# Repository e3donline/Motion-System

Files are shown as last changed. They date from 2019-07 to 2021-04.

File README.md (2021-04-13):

# Motion System
STPs / STLs / DXFs / PDFs

Copyright (C) E3D-Online Ltd (e3d-online.com) These files are free hardware you can redistribute it and / or modify it under the terms of the General Public License as published by the Free Software Foundation, either version 3 of the License, or (at your option) any later version.

13/04/21 - Added Bowden Hemera Bracket.

10/02/21 - Adapted MS-ELEC-PANEL from Titan to Hemera.

05/08/19 - Added README.md to the STLs folder  

02/08/19 - Added assembly drawings

31/07/19 - Added step files of printed parts

30/07/19 - Initial Upload

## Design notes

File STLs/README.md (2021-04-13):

Print the required number of parts as listed below.

4 x Spool Bar.stl   (This part can be replaced with a 90mm length of 8mm round bar).

2 x Hemera Bowden Bracket.stl for each Bowden Hemera.

4 x Spool Carrier.stl  
4 x Filament Pick-Up.stl  
1 x IEC Bracket.stl  
1 x IEC Socket.stl  
1 x Motor Cable Cover.stl  
1 x PSU Duct.stl  
1 x Cable Blank.stl  
1 x Wiper.stl  
  
Typical slicer settings.  
  
0.20 Layer height.  
0.40 Nozzle.  
3 Perimeters.  
5 Top Layers.  
5 Bottom Layers.  
12% Infil.  
  
Print with your favourite material.

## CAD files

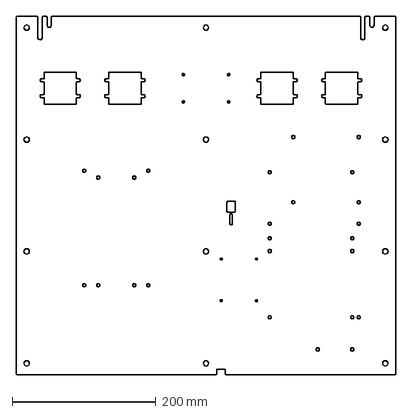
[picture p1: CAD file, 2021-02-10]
DXFs/MS-ELEC-PANEL-PUBLIC-1.3.dxf
529.0 x 499.0 mm

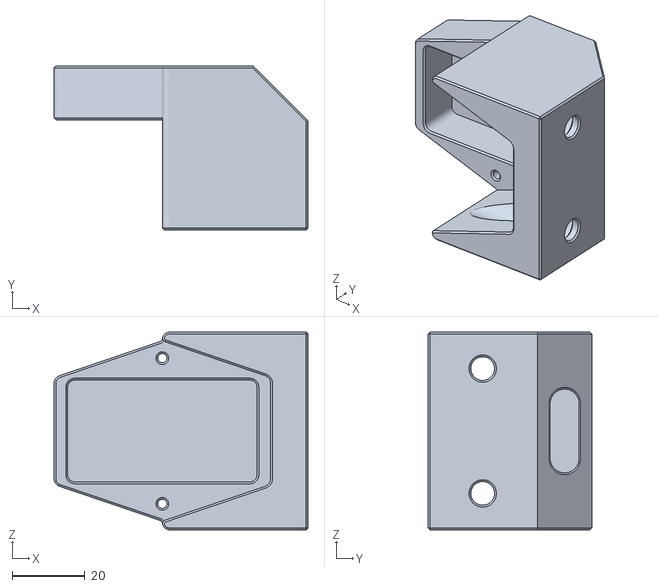
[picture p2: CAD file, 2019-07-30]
STLs/IEC Bracket.stl
69.8 x 45.0 x 54.3

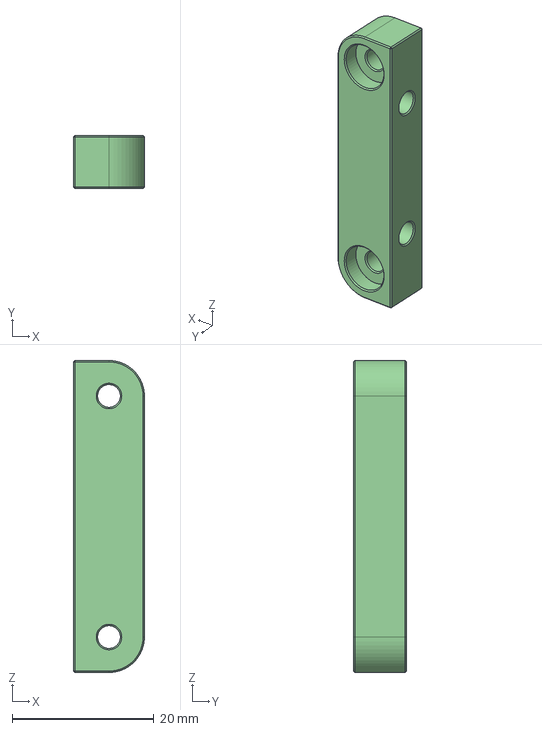
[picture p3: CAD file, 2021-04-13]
STPs/Hemera Bowden Bracket.step
10.0 x 7.50 x 44.0 mm

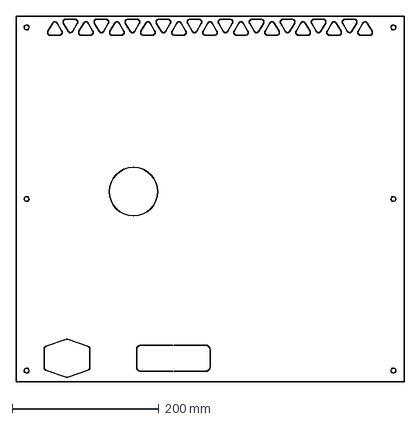
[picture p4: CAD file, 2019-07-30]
DXFs/MS-REAR-PANEL 1.0.dxf
529.0 x 499.0 mm

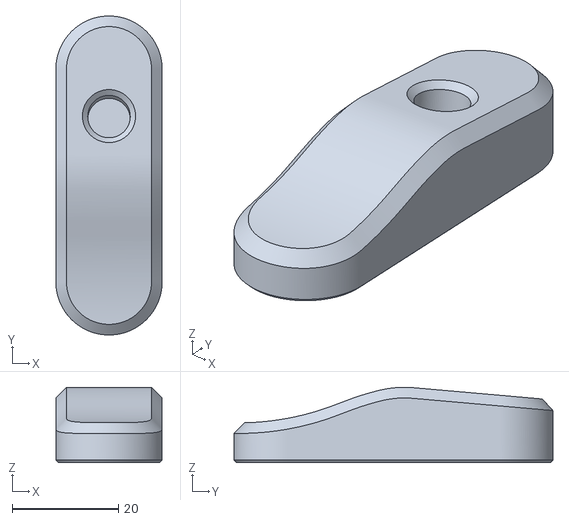
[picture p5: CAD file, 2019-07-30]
STLs/Spool Carrier.stl
20.0 x 60.0 x 14.2

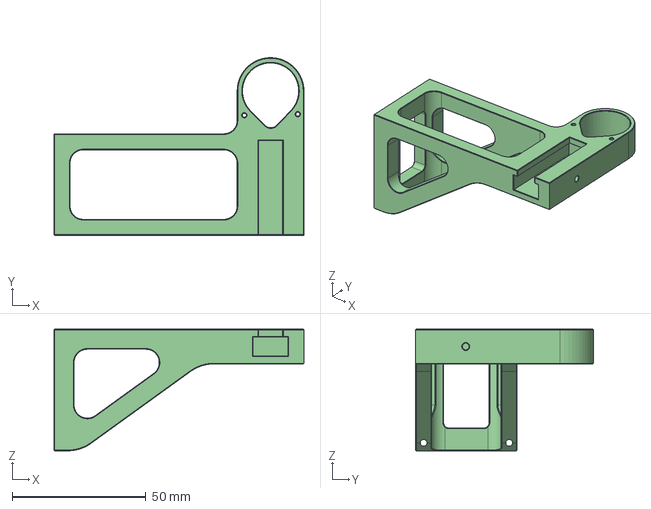
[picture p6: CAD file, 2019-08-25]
STPs/Wiper.step
93.5 x 66.5 x 45.5 mm

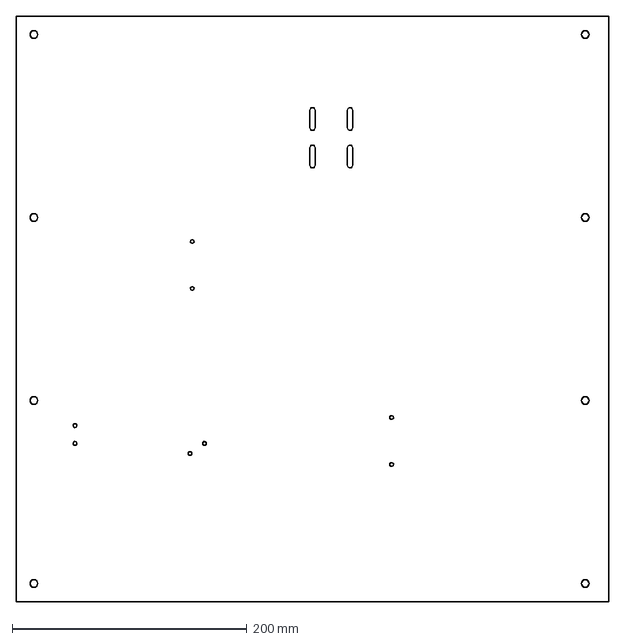
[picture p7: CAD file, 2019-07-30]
DXFs/MS-SIDE-PANEL 1.0.dxf
505.0 x 499.0 mm

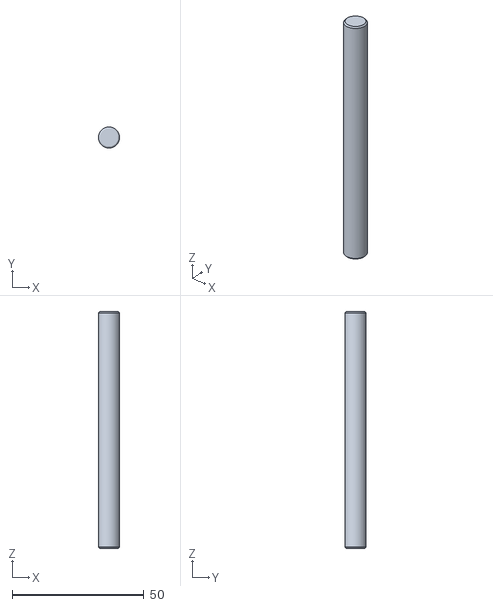
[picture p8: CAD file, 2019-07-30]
STLs/Spool Bar.stl
8.00 x 7.99 x 90.0

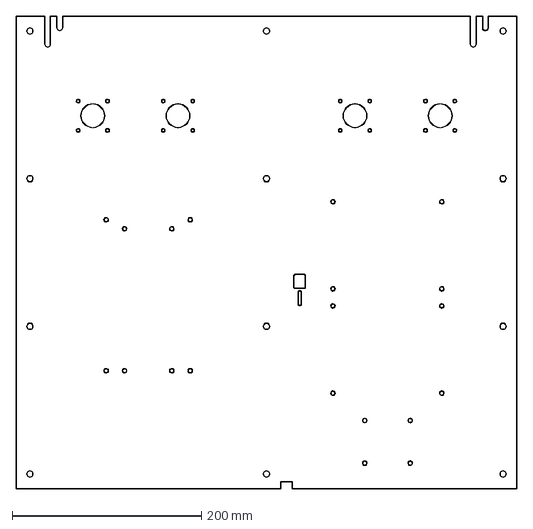
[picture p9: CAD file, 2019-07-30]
DXFs/MS-ELEC-PANEL 1.0.dxf
529.0 x 499.0 mm

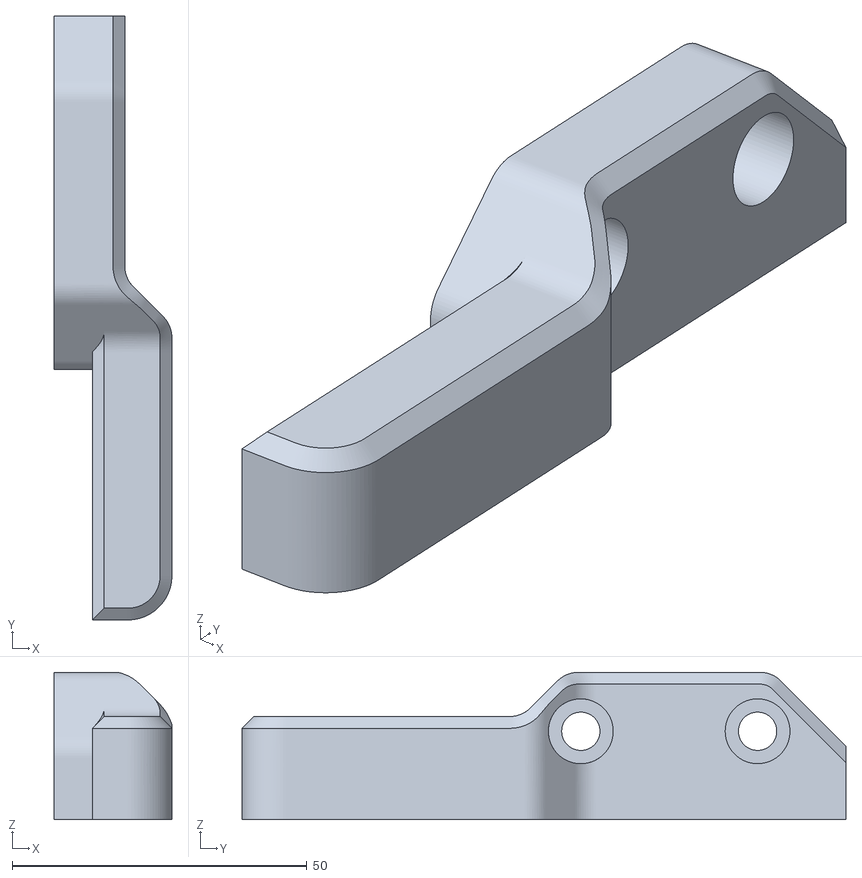
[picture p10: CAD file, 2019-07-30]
STLs/Motor Cable Cover.stl
20.0 x 102.5 x 25.0

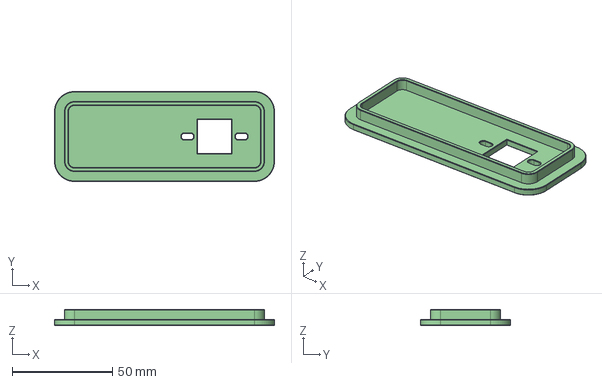
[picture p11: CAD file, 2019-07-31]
STPs/Cable Blank RJ45.step
110.0 x 45.0 x 8.00 mm

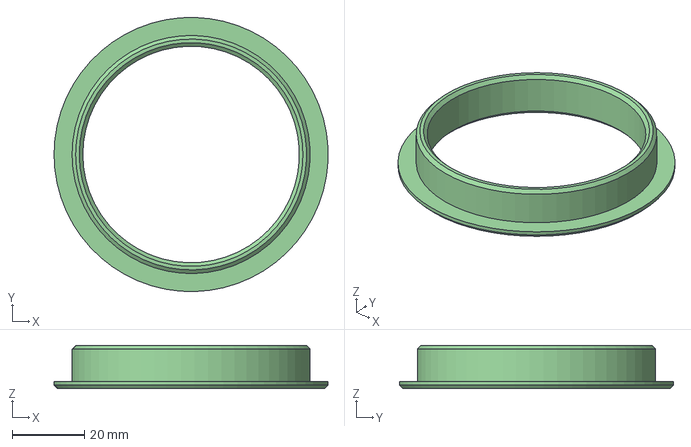
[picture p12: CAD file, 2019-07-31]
STPs/PSU Duct.step
75.9 x 76.0 x 12.0 mm

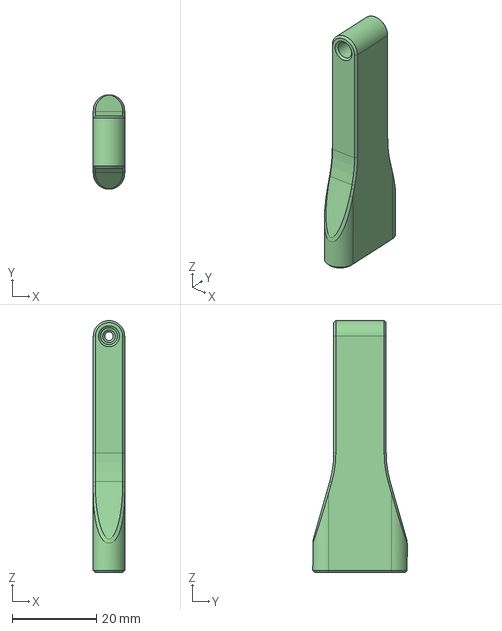
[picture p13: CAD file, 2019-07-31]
STPs/Filament Pick-Up.step
7.50 x 22.5 x 60.0 mm

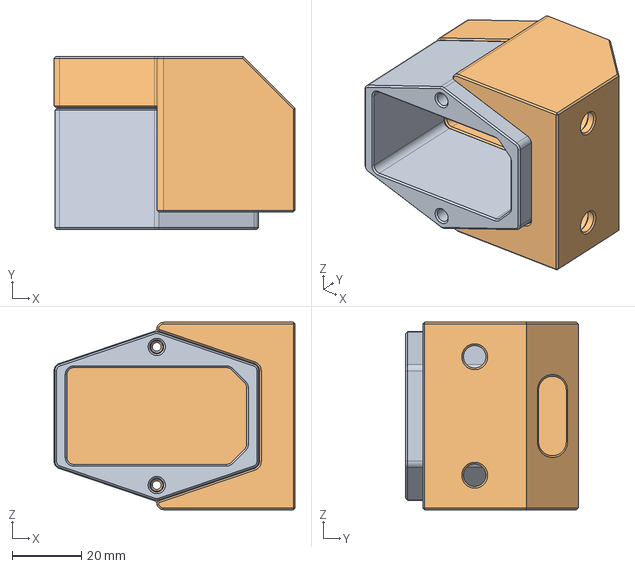
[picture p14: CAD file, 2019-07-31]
STPs/IEC Socket.step
69.8 x 50.0 x 54.3 mm

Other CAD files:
STPs/Spool Carrier Bracket .step
STPs/Z-Axis Motor Cable Cover.step
STPs/Cable Blank.step
STPs/Nozzle Brush.step
DXFs/MS-BASE-PLATE 1.4.dxf
DXFs/MS-TOP-PLATE 1.6.dxf
STLs/Cable Blank.stl
STLs/Filament Pick-Up.stl
STLs/Hemera Bowden Bracket.stl
STLs/IEC Socket.stl
STLs/PSU Duct.stl
STLs/Wiper.stl
STPs/8X90 Spool Bar.step
STPs/MS-BASE-PLATE 1.4.step
STPs/MS-BED-BRACKET 1.4.step
STPs/MS-BED-PLATE 1.3.step
STPs/MS-BELT-CLAMP-IM 1.2.step
STPs/MS-LONG-PULLEY-STANDOFF 1.3.step
STPs/MS-MOTOR-SPACE-LONG 1.1.step
STPs/MS-MOTOR-SPACE-SHORT 1.1.step
STPs/MS-SHAFT-BOLT 1.4.step
STPs/MS-SHORT-PULLEY-STANDOFF 1.3.step
STPs/MS-SOFF-M3-FF-24L 1.1.step
STPs/MS-TENSION-ARM 1.0.step
STPs/MS-TENSION-BLOCK 1.1.step
STPs/MS-TOP-PLATE 1.6.step
STPs/MS-X-BAR-ALU 1.3.step
STPs/MS-X-BELT-PLATE 1.6.step
STPs/MS-X-BLOCK 1.3.step
STPs/MS-X-SPACER 1.1.step
STPs/MS-XY-STOP 1.1.step
STPs/MS-Z-MOTOR-BRACKET 1.1.step
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

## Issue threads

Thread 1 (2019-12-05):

STEP Assemblies

Parallax91, 2019-12-05:
Would it be possible to add a STEP of the full assembly? STEPs of the major sub-assemblies might be equally useful. I understand that this makes it harder to keep the repository up to date, but it would be nice. The same goes for the tool changer, but I won't post this request twice.

e3donline, 2019-12-06:
A member of the community has already done this | https://www.thingiverse.com/thing:3880296

Closed 2019-12-06.

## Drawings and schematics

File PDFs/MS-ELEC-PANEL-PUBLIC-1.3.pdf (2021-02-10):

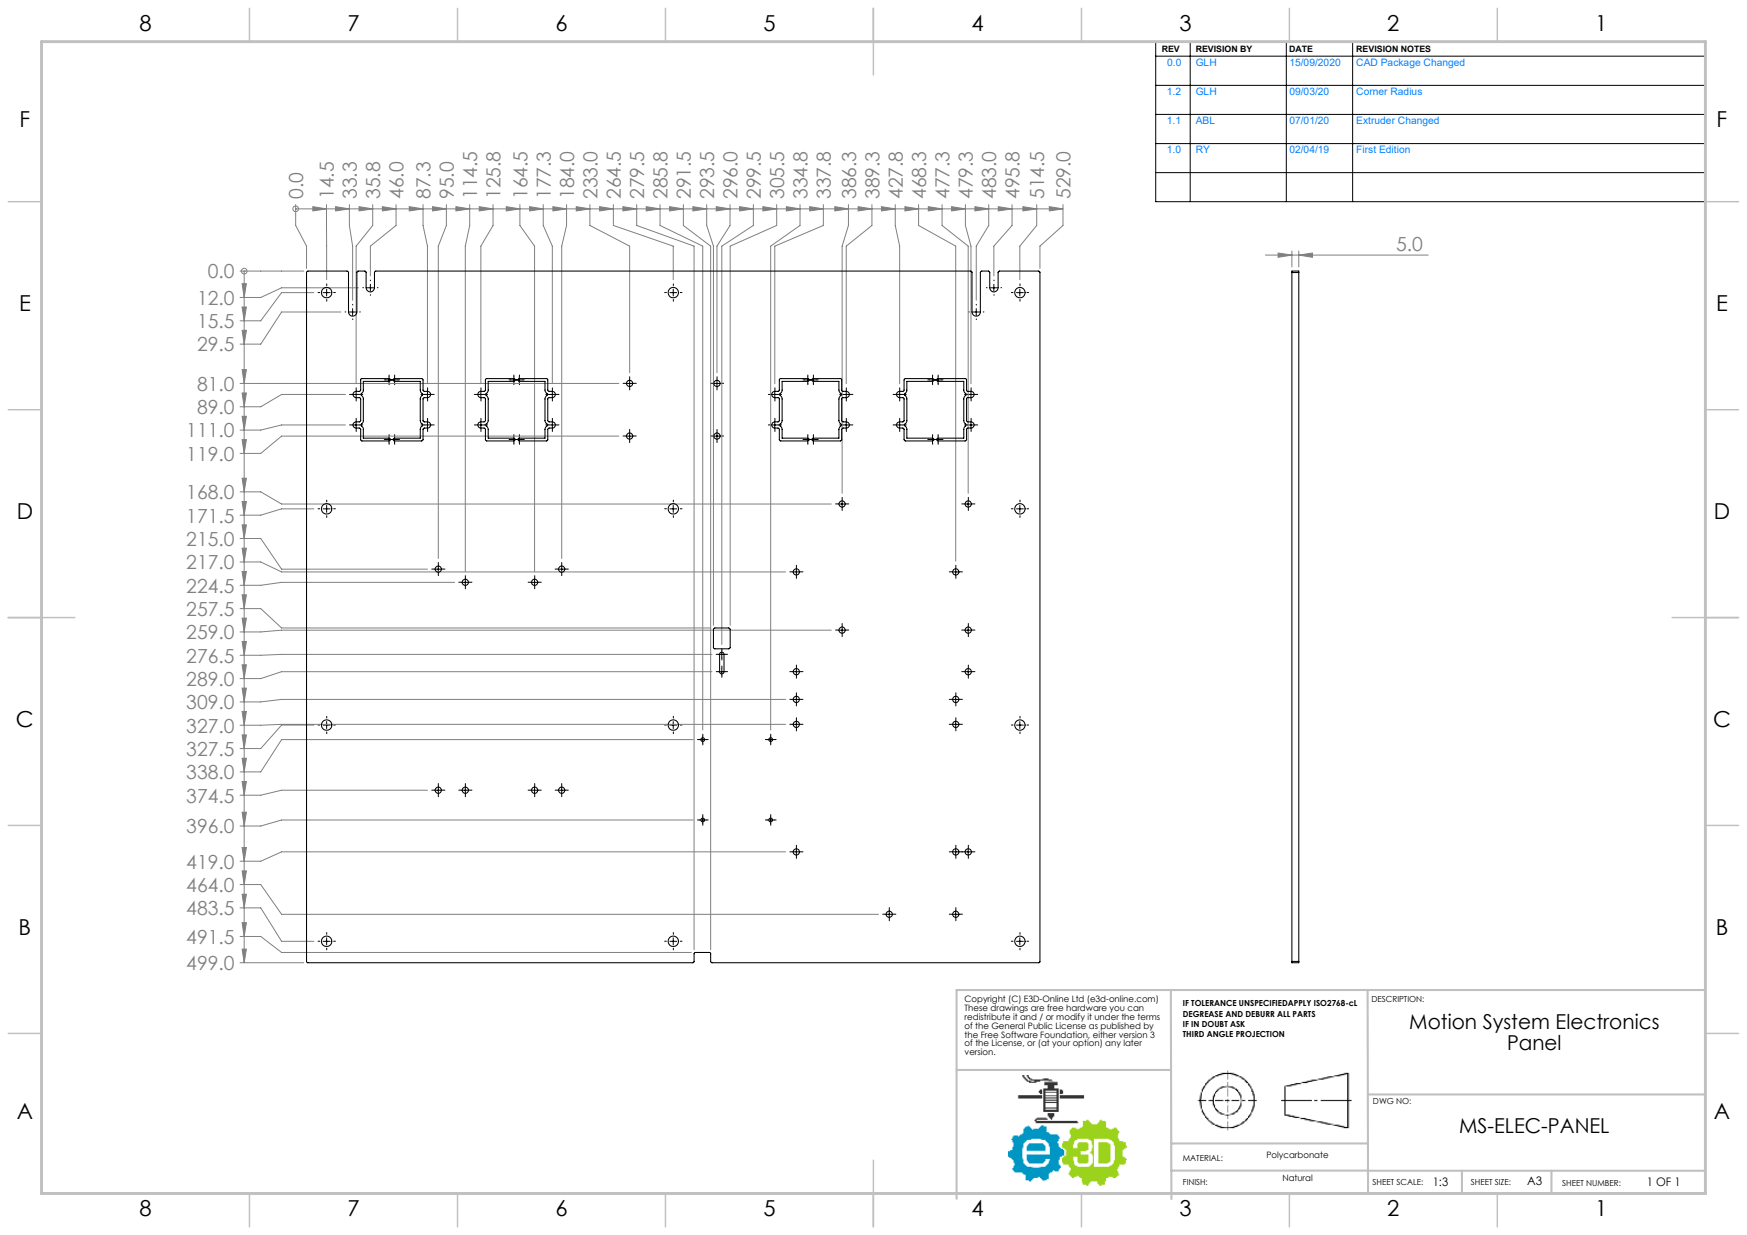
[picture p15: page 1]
DWG NO:; SHEET SCALE:; SHEET SIZE:; SHEET NUMBER:

REV | REVISION BY | DATE | REVISION NOTES
0.0 | GLH | 15/09/2020 | CAD Package Changed

1.2 | GLH | 09/03/20 | Corner Radius

1.1 | ABL | 07/01/20 | Extruder Changed

1.0 | RY | 02/04/19 | First Edition

Copyright (C) E3D-Online Ltd (e3d-online.com)
These drawings are free hardware you can
redistribute it and / or modify it under the terms
of the General Public License as published by
the Free Software Foundation, either version 3
of the License, or (at your option) any later
version.

IF TOLERANCE UNSPECIFIEDAPPLY ISO2768-cL
DEGREASE AND DEBURR ALL PARTS
IF IN DOUBT ASK
THIRD ANGLE PROJECTION

DESCRIPTION:
Motion System Electronics

MS-ELEC-PANEL

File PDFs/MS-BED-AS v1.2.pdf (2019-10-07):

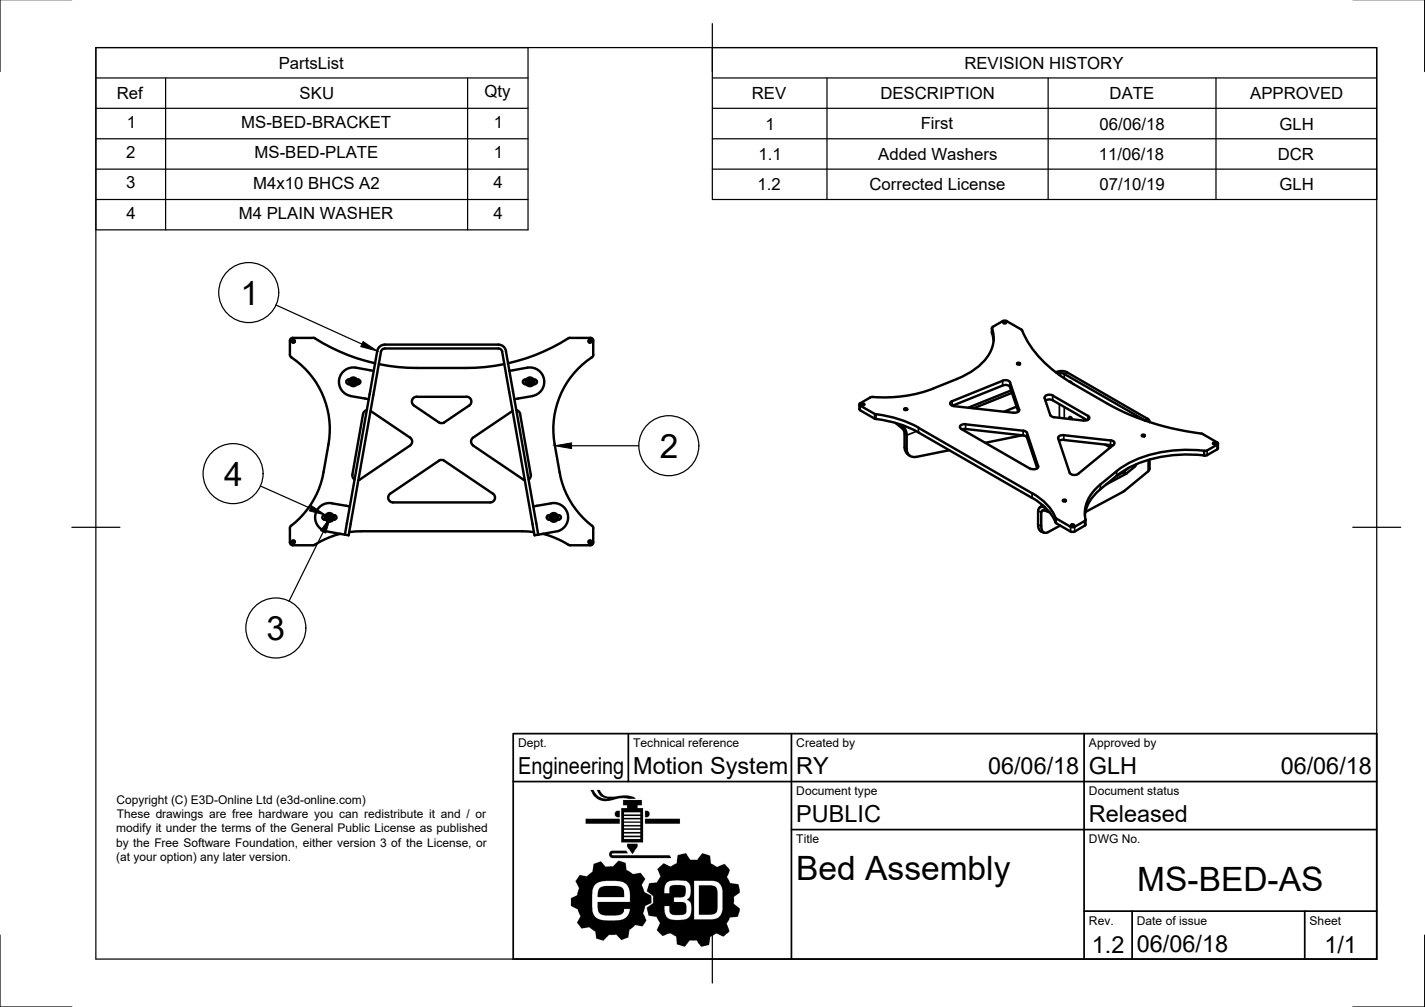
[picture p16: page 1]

PartsList | | REVISION HISTORY

Ref | SKU | Qty | REV | DESCRIPTION | DATE | APPROVED
1 | MS-BED-BRACKET | 1 | 1 | First | 06/06/18 | GLH
2 | MS-BED-PLATE | 1 | 1.1 | Added Washers | 11/06/18 | DCR
3 | M4x10 BHCS A2 | 4 | 1.2 | Corrected License | 07/10/19 | GLH
4 | M4 PLAIN WASHER | 4

Dept. Engineering | Technical reference Motion System | Created by RY 06/06/18 | Approved by GLH 06/06/18

Document type PUBLIC | Document status Released

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

Title | DWG No. MS-BED-AS Bed Assembly

Rev. 1.2 | Date of issue 06/06/18 | Sheet 1/1

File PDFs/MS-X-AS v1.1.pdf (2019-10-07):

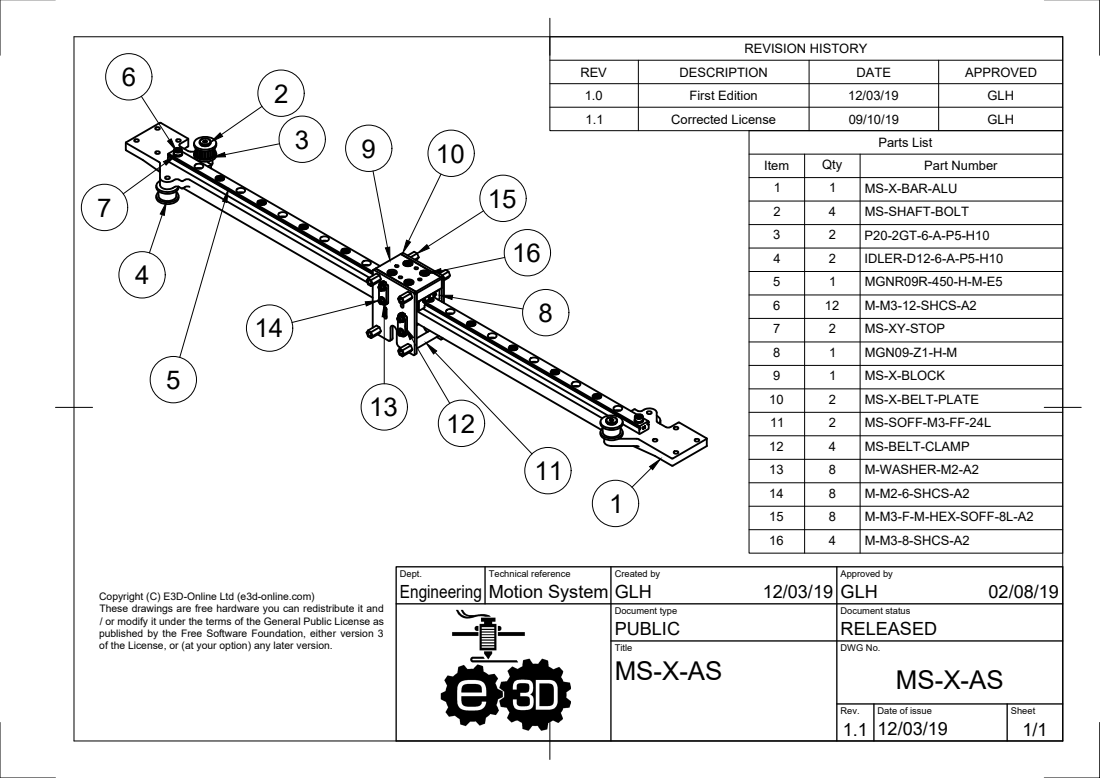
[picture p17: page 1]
Parts List

REVISION HISTORY

REV | DESCRIPTION | DATE | APPROVED
1.0 | First Edition | 12/03/19 | GLH
1.1 | Corrected License | 09/10/19 | GLH

Item | Qty | Part Number
1 | 1 | MS-X-BAR-ALU
2 | 4 | MS-SHAFT-BOLT
3 | 2 | P20-2GT-6-A-P5-H10
4 | 2 | IDLER-D12-6-A-P5-H10
5 | 1 | MGNR09R-450-H-M-E5
6 | 12 | M-M3-12-SHCS-A2
7 | 2 | MS-XY-STOP
8 | 1 | MGN09-Z1-H-M
9 | 1 | MS-X-BLOCK
10 | 2 | MS-X-BELT-PLATE
11 | 2 | MS-SOFF-M3-FF-24L
12 | 4 | MS-BELT-CLAMP
13 | 8 | M-WASHER-M2-A2
14 | 8 | M-M2-6-SHCS-A2
15 | 8 | M-M3-F-M-HEX-SOFF-8L-A2
16 | 4 | M-M3-8-SHCS-A2

Dept. Engineering | Technical reference Motion System | Created by GLH 12/03/19 | Approved by GLH 02/08/19

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

Document type PUBLIC | Document status RELEASED

of the License, or (at your option) any later version.

Title MS-X-AS | DWG No. MS-X-AS

Rev. 1.1 | Date of issue 12/03/19 | Sheet 1/1

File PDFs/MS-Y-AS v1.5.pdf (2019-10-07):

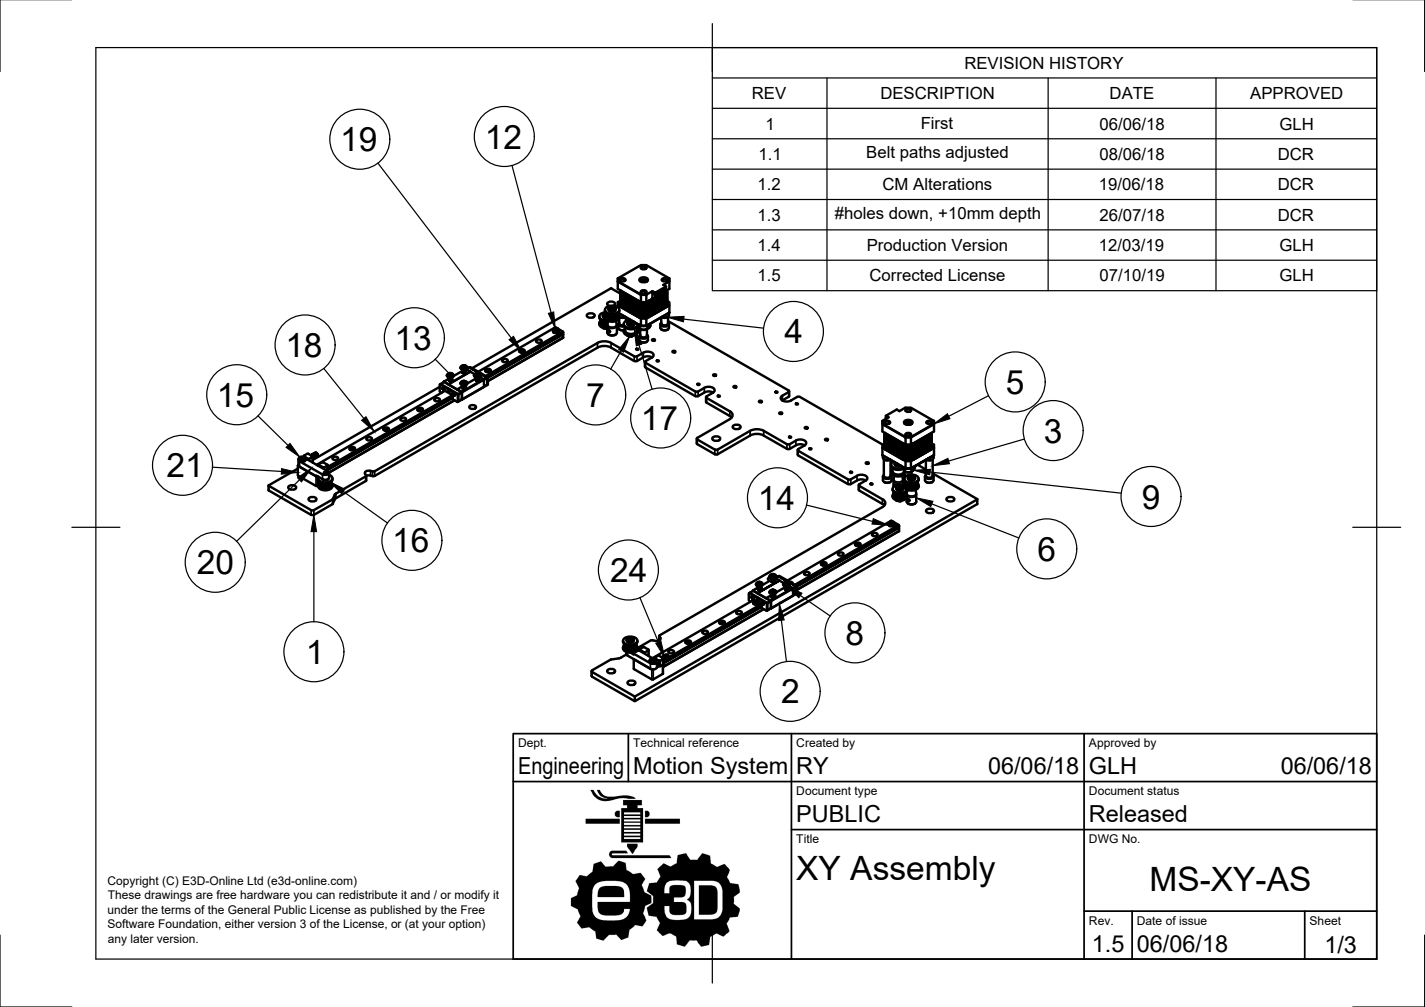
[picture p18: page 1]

REVISION HISTORY

REV | DESCRIPTION | DATE | APPROVED
1 | First | 06/06/18 | GLH
1.1 | Belt paths adjusted | 08/06/18 | DCR

1.2 | CM Alterations | 19/06/18 | DCR
1.3 | #holes down, +10mm depth | 26/07/18 | DCR

1.4 | Production Version | 12/03/19 | GLH
1.5 | Corrected License | 07/10/19 | GLH

Dept. Engineering | Technical reference Motion System | Created by RY 06/06/18 | Approved by GLH 06/06/18

Document type PUBLIC | Document status Released

Title | DWG No. MS-XY-AS XY Assembly

Copyright (C) E3D-Online Ltd (e3d-online.com)
These drawings are free hardware you can redistribute it and / or modify it
under the terms of the General Public License as published by the Free
Software Foundation, either version 3 of the License, or (at your option)
any later version.

Rev. 1.5 | Date of issue 06/06/18 | Sheet 1/3

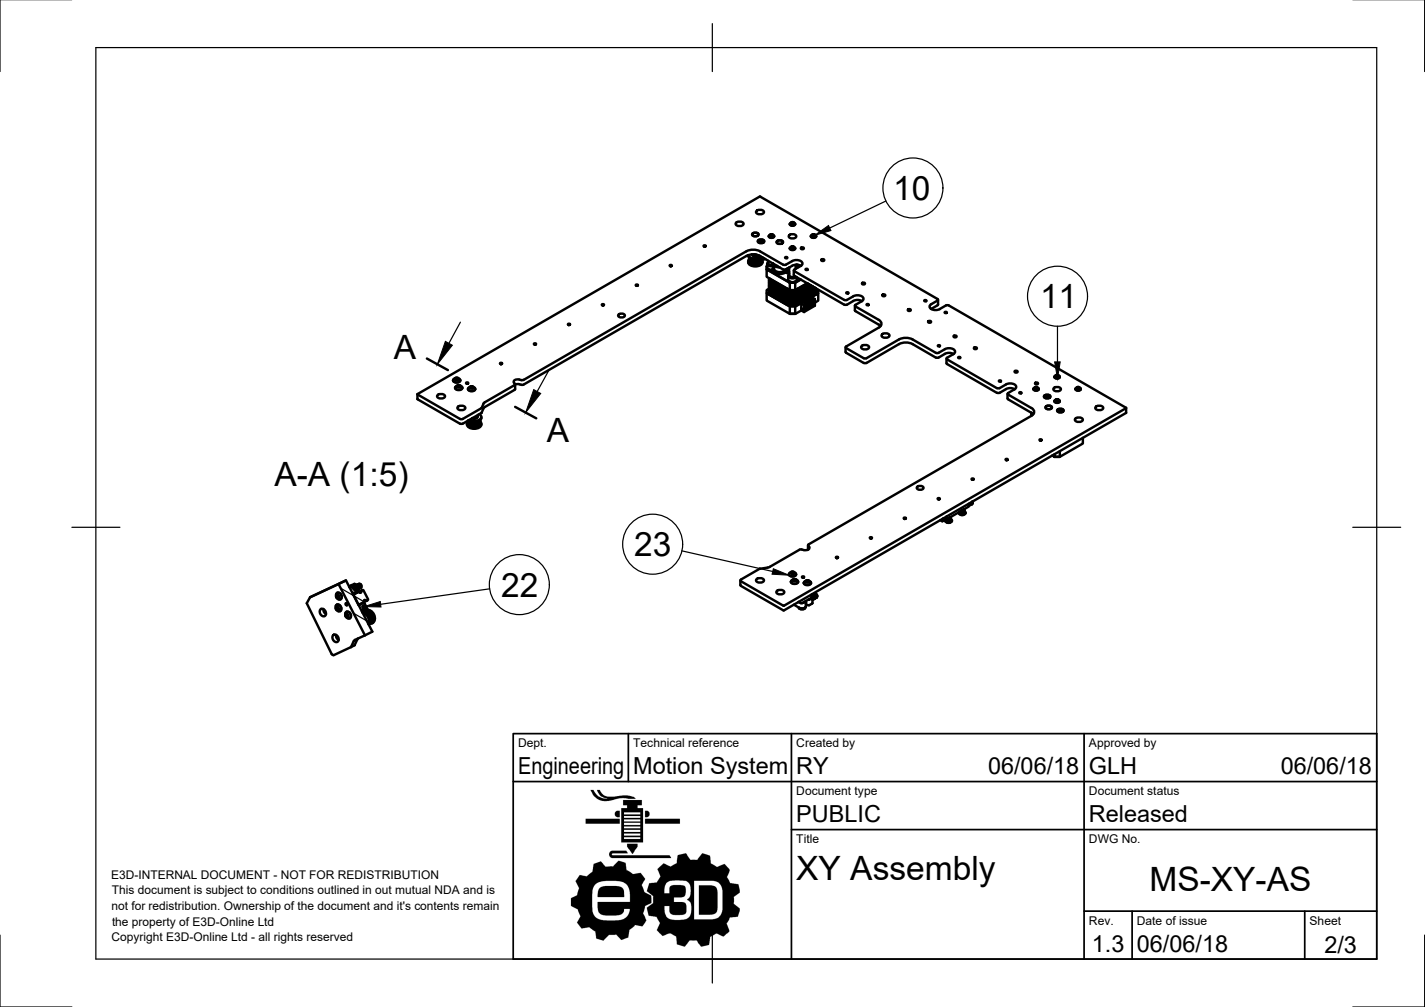
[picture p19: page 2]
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

Document type PUBLIC | Document status Released

Title | DWG No. MS-XY-AS XY Assembly

E3D-INTERNAL DOCUMENT - NOT FOR REDISTRIBUTION
This document is subject to conditions outlined in out mutual NDA and is
not for redistribution. Ownership of the document and it's contents remain
the property of E3D-Online Ltd
Copyright E3D-Online Ltd - all rights reserved

Rev. 1.3 | Date of issue 06/06/18 | Sheet 2/3

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

## Parts List

Item | Qty | Part Number
1 | 1 | MS-TOP-PLATE
2 | 2 | MGN12H-Z0-H-M
3 | 4 | MS-MOTOR-SPACE-LONG
4 | 4 | MS-MOTOR-SPACE-SHORT
5 | 2 | MS17HD2P4200
6 | 3 | MS-LONG-PULLEY-STANDOFF
7 | 3 | MS-SHORT-PULLEY-STANDOFF
8 | 8 | M-WASHER-M3-A2
9 | 2 | GT2 16T 5mm Bore Pulley
10 | 4 | M-M3-45-BHCS-A2
11 | 4 | M-M3-30-BHCS-A2
12 | 4 | M-M3-12-SHCS-A2
13 | 8 | M-M3-10-BHCS-A2
14 | 4 | MS-XY-STOP
15 | 10 | MS-SHAFT-BOLT
16 | 6 | P20-2GT-6-A-P5-H10
17 | 2 | IDLER-D12-6-A-P5-H10
18 | 2 | MGNR12R-360-H-M-E5
19 | 12 | M-M3-8-SHCS-A2
20 | 2 | MS-TENSION-ARM
21 | 2 | MS-TENSION-BLOCK
22 | 2 | M-M4-8-SHGS-A2
23 | 6 | M-M4-12-BHCS-A2
24 | 2 | M-M4-16-SHGS-A2

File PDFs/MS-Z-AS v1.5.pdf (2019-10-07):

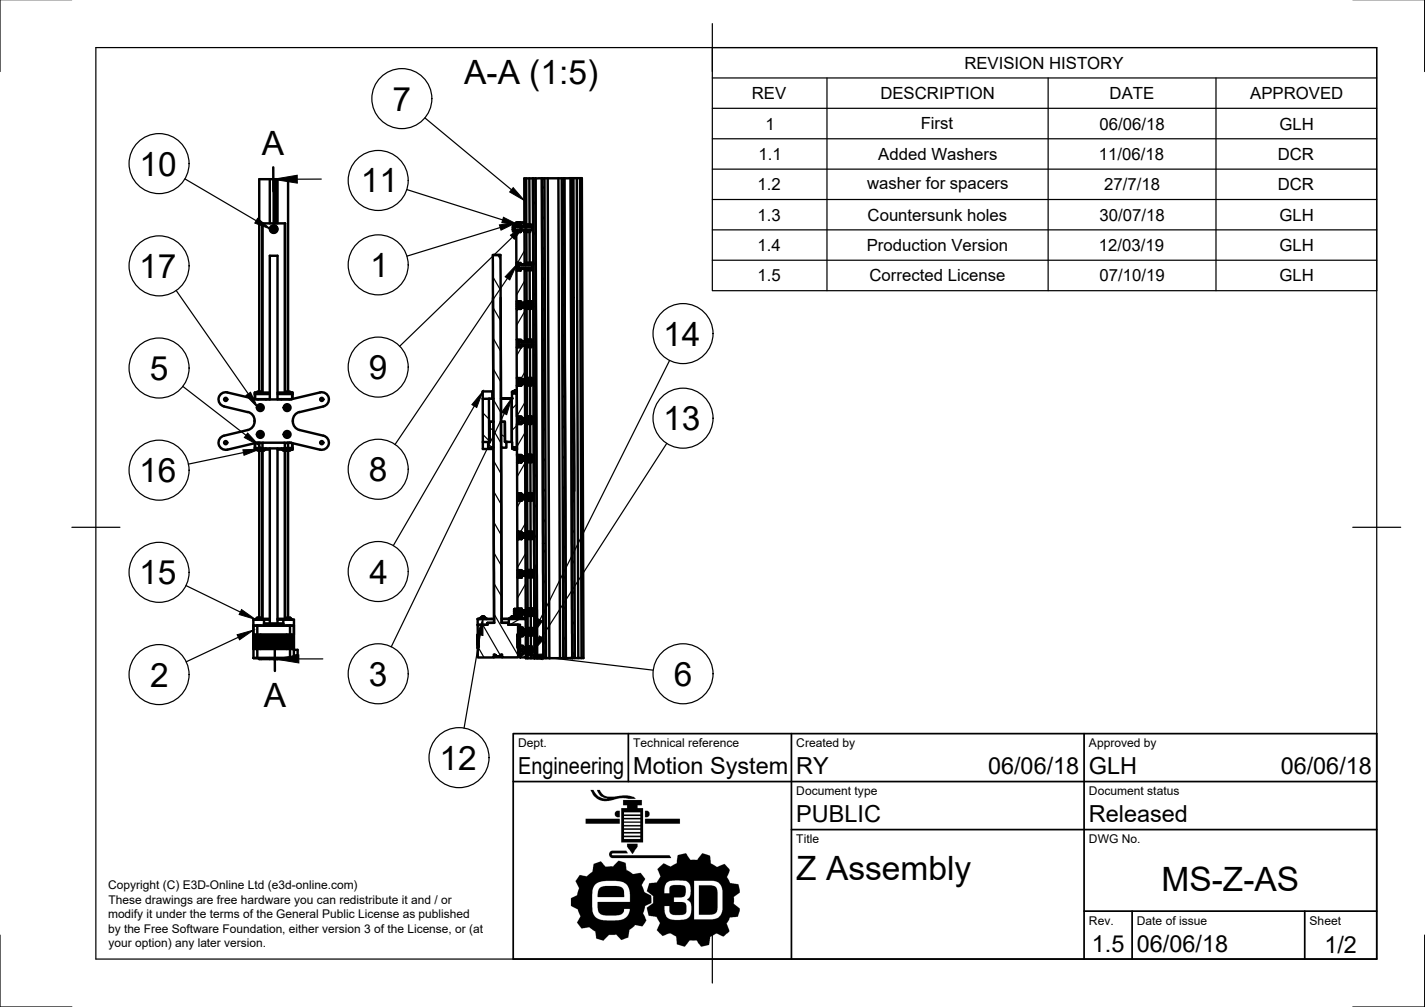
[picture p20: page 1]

A-A (1:5) A | REVISION HISTORY

REV | DESCRIPTION | DATE | APPROVED
1 | First | 06/06/18 | GLH
1.1 | Added Washers | 11/06/18 | DCR
1.2 | washer for spacers | 27/7/18 | DCR

1.3 | Countersunk holes | 30/07/18 | GLH
1.4 | Production Version | 12/03/19 | GLH
1.5 | Corrected License | 07/10/19 | GLH

Dept. Engineering | Technical reference Motion System | Created by RY 06/06/18 | Approved by GLH 06/06/18

Document type PUBLIC | Document status Released

Title | DWG No. MS-Z-AS Z Assembly

Copyright (C) E3D-Online Ltd (e3d-online.com)
These drawings are free hardware you can redistribute it and / or
modify it under the terms of the General Public License as published
by the Free Software Foundation, either version 3 of the License, or (at
your option) any later version.

Rev. 1.5 | Date of issue 06/06/18 | Sheet 1/2

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

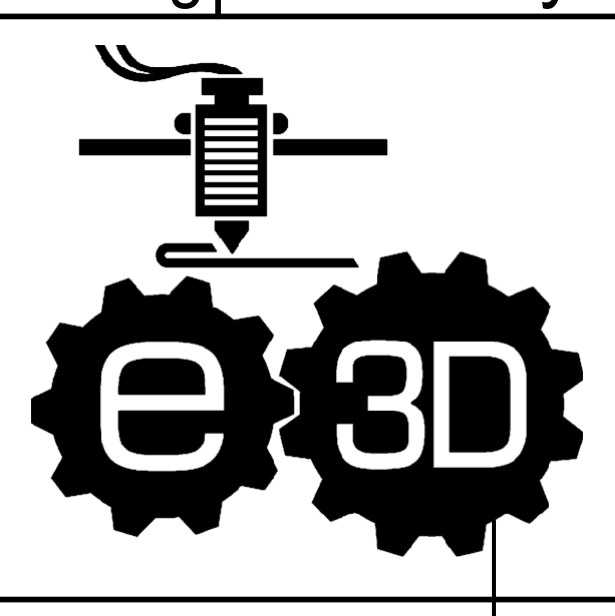
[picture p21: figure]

| | Document type PUBLIC | Document status Released
| | Title | DWG No. MS-Z-AS Z Assembly
Rev. 1.3 | Date of issue 06/06/18 | Sheet 2/2
Parts List | Parts List
Item | Qty | Part Number | Item | Qty | Part Number
1 | 1 | MGWR12R-412-H-M-E6 | 10 | 2 | M-M4-16-SHCS-A2
2 | 1 | NEMA 17 385mm Intergrated Leadscrew | 11 | 2 | MS-Z-STOP
3 | 1 | MGW12H-Z1-H-M | 12 | 4 | M-M3-10-BHCS-A2
4 | 1 | MS-Z-NUT-BRACKET | 13 | 2 | M-M5-10-LOW-SHCS-A2
5 | 1 | Anti-Backlash Nut | 14 | 2 | M5 T-NUT
6 | 1 | MS-Z-MOTOR-BRACKET | 15 | 6 | M-WASHER-M3-A2
7 | 1 | MS-VERTICAL | 16 | 2 | M-M3-12-BHCS-A2
8 | 9 | M-M4-12-SHCS-A2 | 17 | 4 | M-M3-25-SHCS-A2
9 | 11 | M4 T-NUT

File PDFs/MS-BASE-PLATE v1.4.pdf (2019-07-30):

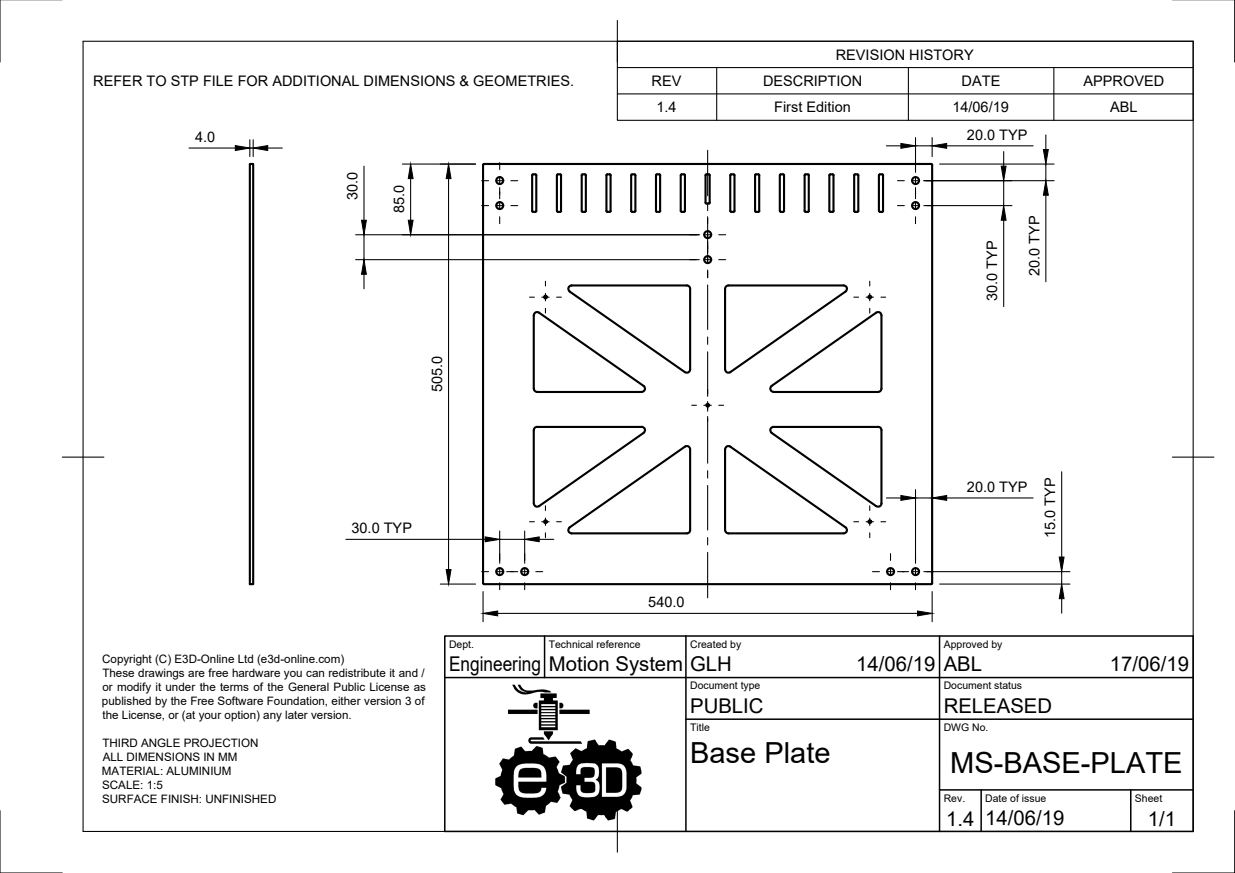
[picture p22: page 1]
30.0 TYP; 20.0 TYP 20.0 TYP 15.0 TYP20.0 TYP 30.0

REVISION HISTORY

REFER TO STP FILE FOR ADDITIONAL DIMENSIONS & GEOMETRIES. 505.0

REV | DESCRIPTION | DATE | APPROVED
1.4 | First Edition | 14/06/19 | ABL

Dept. Engineering | Technical reference Motion System | Created by GLH 14/06/19 | Approved by ABL 17/06/19

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

Document type PUBLIC | Document status RELEASED

the License, or (at your option) any later version.

Title | DWG No. MS-BASE-PLATE Base Plate

THIRD ANGLE PROJECTION
ALL DIMENSIONS IN MM
MATERIAL: ALUMINIUM
SCALE: 1:5
SURFACE FINISH: UNFINISHED

Rev. 1.4 | Date of issue 14/06/19 | Sheet 1/1

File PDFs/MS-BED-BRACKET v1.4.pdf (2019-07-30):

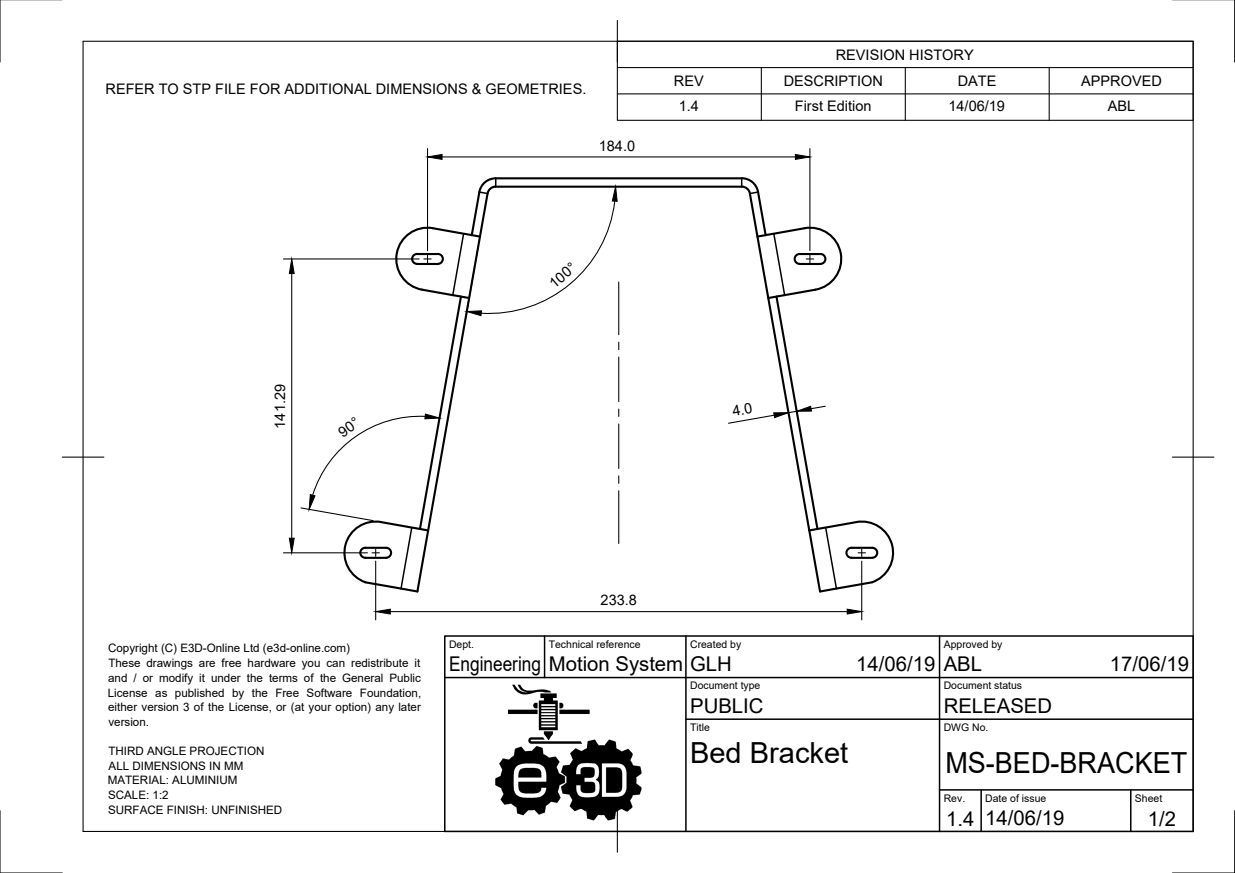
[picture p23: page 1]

REVISION HISTORY

REV | DESCRIPTION | DATE | APPROVED
1.4 | First Edition | 14/06/19 | ABL

REFER TO STP FILE FOR ADDITIONAL DIMENSIONS & GEOMETRIES.

Copyright (C) E3D-Online Ltd (e3d-online.com)
These drawings are free hardware you can redistribute it
and / or modify it under the terms of the General Public
License as published by the Free Software Foundation,
either version 3 of the License, or (at your option) any later
version.

Dept. Engineering | Technical reference Motion System | Created by GLH 14/06/19 | Approved by ABL 17/06/19

Document type PUBLIC | Document status RELEASED

Title | DWG No. MS-BED-BRACKET Bed Bracket

THIRD ANGLE PROJECTION
ALL DIMENSIONS IN MM
MATERIAL: ALUMINIUM
SCALE: 1:2
SURFACE FINISH: UNFINISHED

Rev. 1.4 | Date of issue 14/06/19 | Sheet 1/2

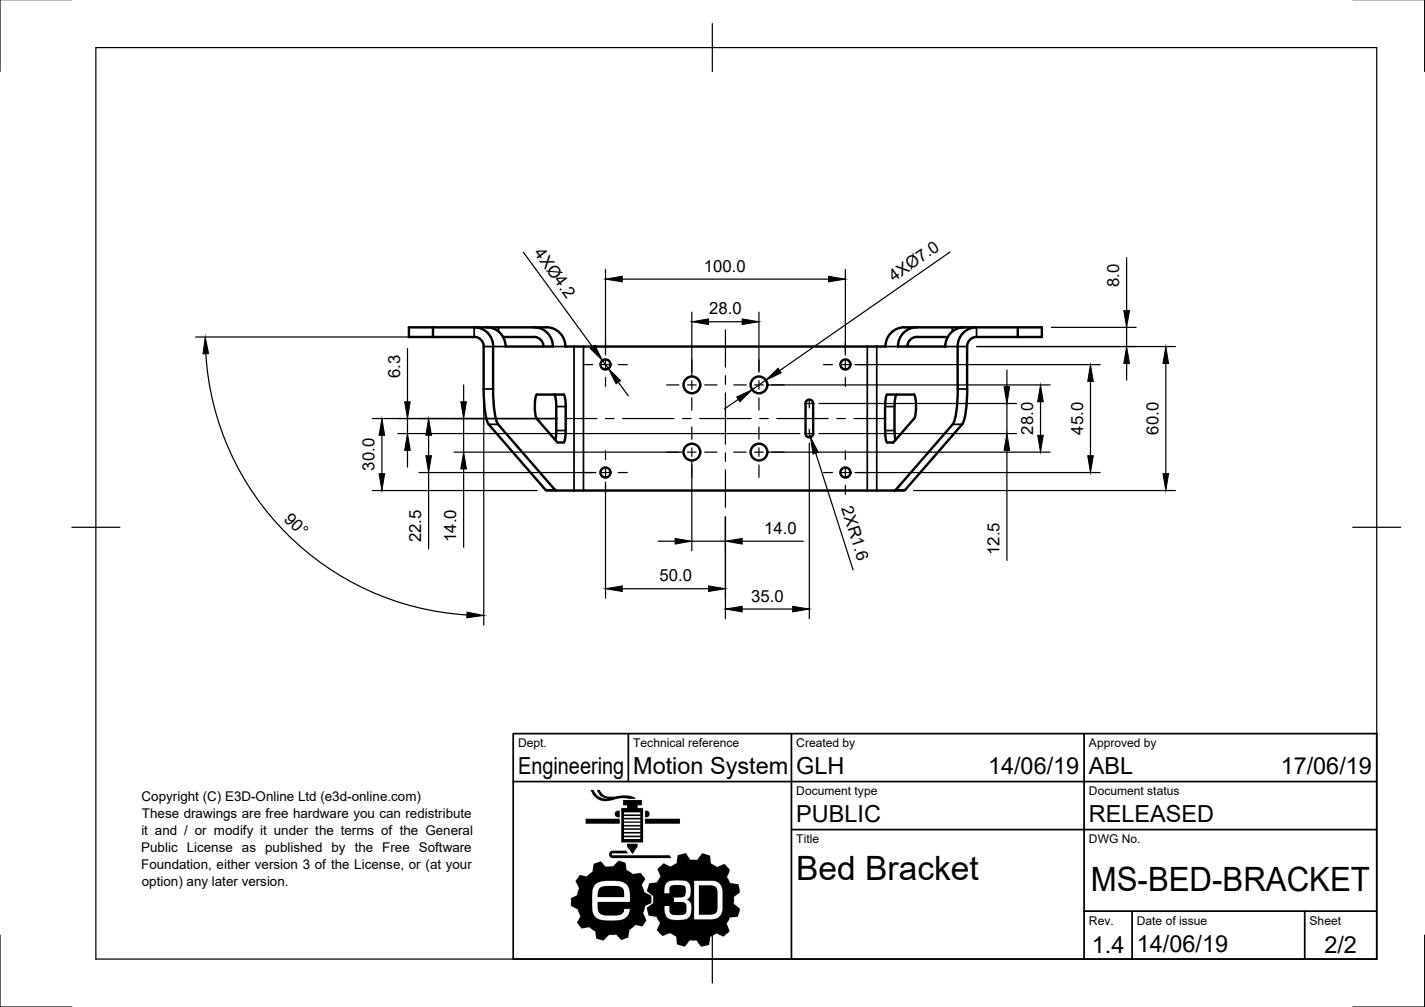
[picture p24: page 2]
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

Document type PUBLIC | Document status RELEASED

Title | DWG No. MS-BED-BRACKET Bed Bracket

Rev. 1.4 | Date of issue 14/06/19 | Sheet 2/2

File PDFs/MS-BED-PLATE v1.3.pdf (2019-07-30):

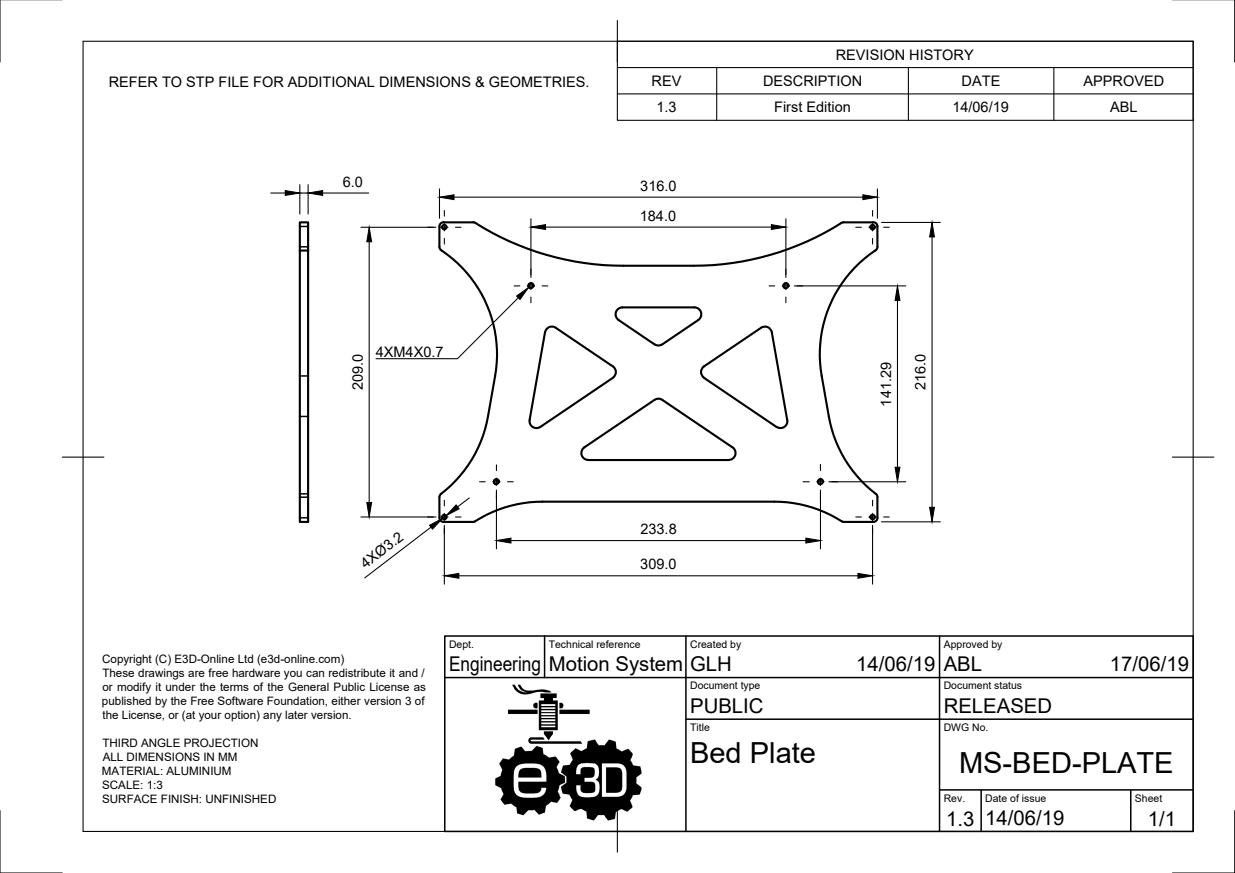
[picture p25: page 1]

REVISION HISTORY

REV | DESCRIPTION | DATE | APPROVED
1.3 | First Edition | 14/06/19 | ABL

REFER TO STP FILE FOR ADDITIONAL DIMENSIONS & GEOMETRIES.

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

Document type PUBLIC | Document status RELEASED

the License, or (at your option) any later version.

Title | DWG No. MS-BED-PLATE Bed Plate

THIRD ANGLE PROJECTION
ALL DIMENSIONS IN MM
MATERIAL: ALUMINIUM
SCALE: 1:3
SURFACE FINISH: UNFINISHED

Rev. 1.3 | Date of issue 14/06/19 | Sheet 1/1

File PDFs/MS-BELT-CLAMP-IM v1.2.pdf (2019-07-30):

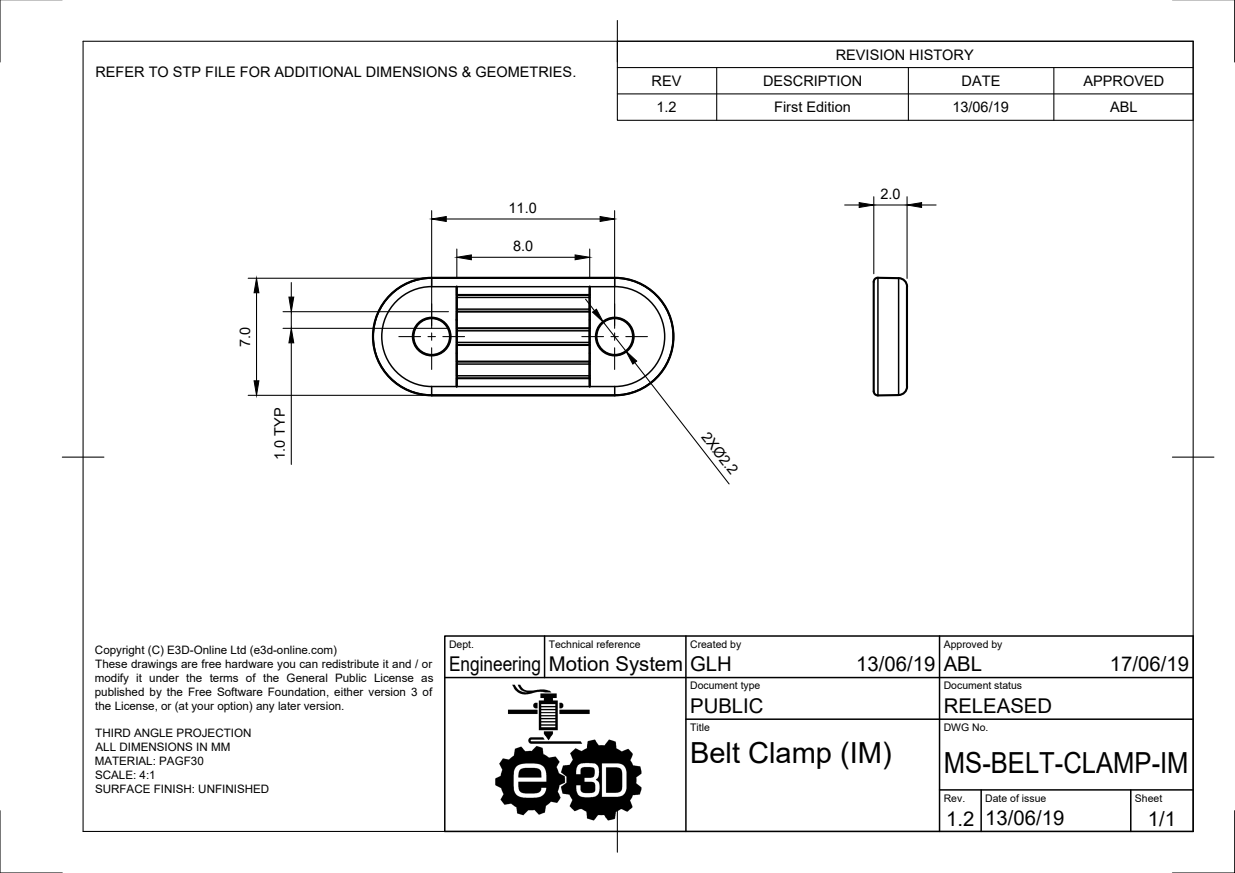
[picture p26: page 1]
8.0 1.0 TYP

REVISION HISTORY

REFER TO STP FILE FOR ADDITIONAL DIMENSIONS & GEOMETRIES.

REV | DESCRIPTION | DATE | APPROVED
1.2 | First Edition | 13/06/19 | ABL

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

Dept. Engineering | Technical reference Motion System | Created by GLH 13/06/19 | Approved by ABL 17/06/19

Document type PUBLIC | Document status RELEASED

the License, or (at your option) any later version.

THIRD ANGLE PROJECTION
ALL DIMENSIONS IN MM
MATERIAL: PAGF30
SCALE: 4:1
SURFACE FINISH: UNFINISHED

Title Belt Clamp (IM) | DWG No. MS-BELT-CLAMP-IM

Rev. 1.2 | Date of issue 13/06/19 | Sheet 1/1

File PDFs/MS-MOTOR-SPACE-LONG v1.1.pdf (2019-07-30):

Ø3.2 THRU

REVISION HISTORY

REV | DESCRIPTION | DATE | APPROVED
1.1 | First Edition | 14/06/19 | ABL

REFER TO STP FILE FOR ADDITIONAL DIMENSIONS & GEOMETRIES. 34.0

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

Document type PUBLIC | Document status RELEASED

the License, or (at your option) any later version.

Title | DWG No. MS-MOTOR-SPACE-LONG Long Motor Spacer

THIRD ANGLE PROJECTION
ALL DIMENSIONS IN MM
MATERIAL: ALUMINIUM
SCALE: 1:1
SURFACE FINISH: UNFINISHED

Rev. 1.1 | Date of issue 14/06/19 | Sheet 1/1

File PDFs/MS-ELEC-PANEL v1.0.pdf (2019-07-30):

31.0 TYP; 31.0 TYP 90.0 TYP 105.0 15.5 TYP; 156.0 TYP; 250.0 TYP 14.5; 81.0 29.5 12.0 TYP

REVISION HISTORY

REFER TO DXF FILE FOR ADDITIONAL DIMENSIONS & GEOMETRIES. 499.0

REV | DESCRIPTION | DATE | APPROVED
1.0 | First Edition | 14/06/19 | ABL

Dept. Engineering | Technical reference Motion System | Created by GLH 14/06/19 | Approved by ABL 17/06/19

Copyright (C) E3D-Online Ltd (e3d-online.com)
These drawings are free hardware you can redistribute it and / or modify it under the terms of the General Public License as published by the Free Software Foundation, either version 3 of

Document type PUBLIC | Document status RELEASED

the License, or (at your option) any later version.

Title | DWG No. MS-ELEC-PANEL Electronics Panel

THIRD ANGLE PROJECTION
ALL DIMENSIONS IN MM
MATERIAL: ACRYLIC
SCALE: 1:1
SURFACE FINISH: UNFINISHED

Rev. 1.0 | Date of issue 14/06/19 | Sheet 1/2

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

Copyright (C) E3D-Online Ltd (e3d-online.com)
These drawings are free hardware you can redistribute
it and / or modify it under the terms of the General
Public License as published by the Free Software
Foundation, either version 3 of the License, or (at your
option) any later version.

Document type PUBLIC | Document status RELEASED

Title | DWG No. MS-ELEC-PANEL Electronics Panel

Rev. 1.0 | Date of issue 14/06/19 | Sheet 2/2

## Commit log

2019-08-02 Assembly drawings added.
2021-02-10 Adapted to Hemera
    Changed from Titan to Hemera Extruders. Added mounting pattern for Duet 3 & Expansion Boards.
2021-02-10 Adapted to Hemera.
    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
    [MS-ELEC-PANEL-PUBLIC-1.3.dxf]
